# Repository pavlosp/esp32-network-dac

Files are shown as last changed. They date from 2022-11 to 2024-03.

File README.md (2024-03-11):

# ESP32-based network streamer and DAC

## Description

This is my first attempt at a simple, high-quality Digital to Analog Converter (DAC) and network streamer. Design is based around the ESP32 WiFi microcontroller, with a Texas Instruments PCM5122 high-quality DAC.

Schematic and PCB layout designed on KiCad 6.

## Schematic and PCB

Manufacturing files are included for the first iteration of the circuit board.

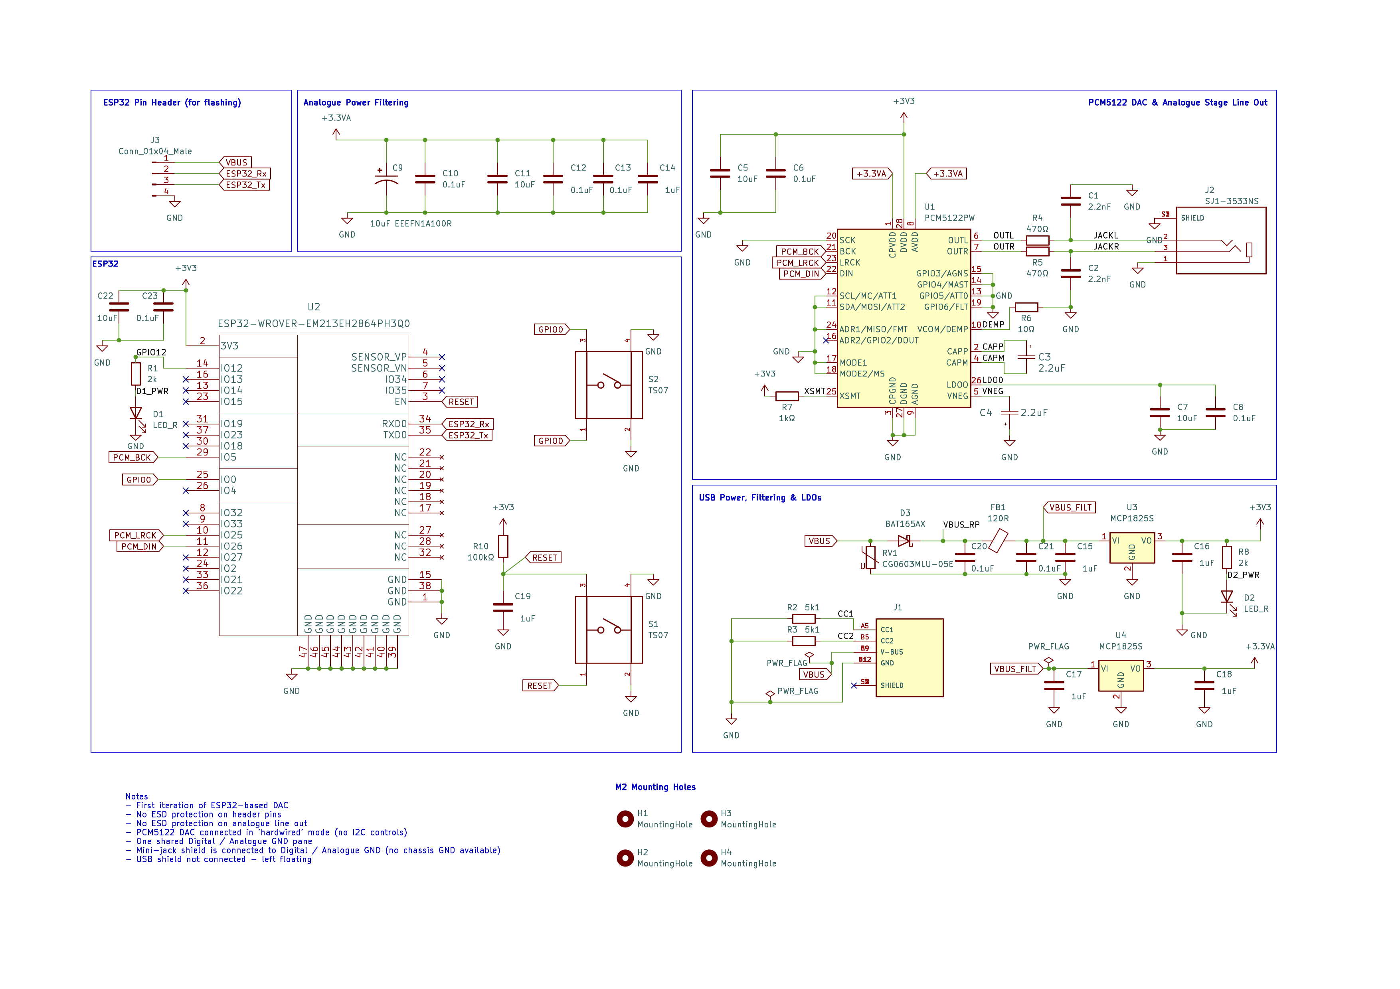
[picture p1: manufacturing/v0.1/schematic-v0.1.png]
Schematic Schematic v0.1

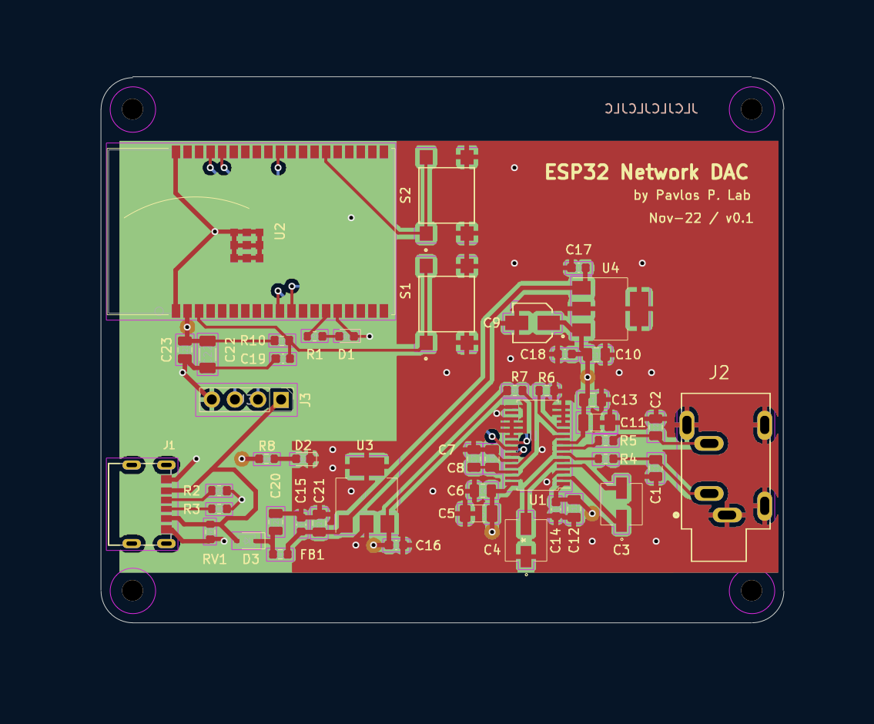
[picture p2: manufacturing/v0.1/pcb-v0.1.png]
PCB PCB v0.1


## Next steps

Refine component selection to simpler components for easier assembly (C0G capacitors).

Longer-term plan: Build on this design to build digital mixer and USB audio interface (potentially with different microcontroller from STM32 range)

## Acknowledgements

Thanks to all the online resources and reference DAC implementations (on TI data sheets). The design can be further improved of course - any suggestions, do let me know.

Many thanks to the [squeezelite-esp32](https://github.com/sle118/squeezelite-esp32) project for the software stack, which includes AirPlay and works with some configuration changes - I2S pinout configuration for digital audio data and clock signals.

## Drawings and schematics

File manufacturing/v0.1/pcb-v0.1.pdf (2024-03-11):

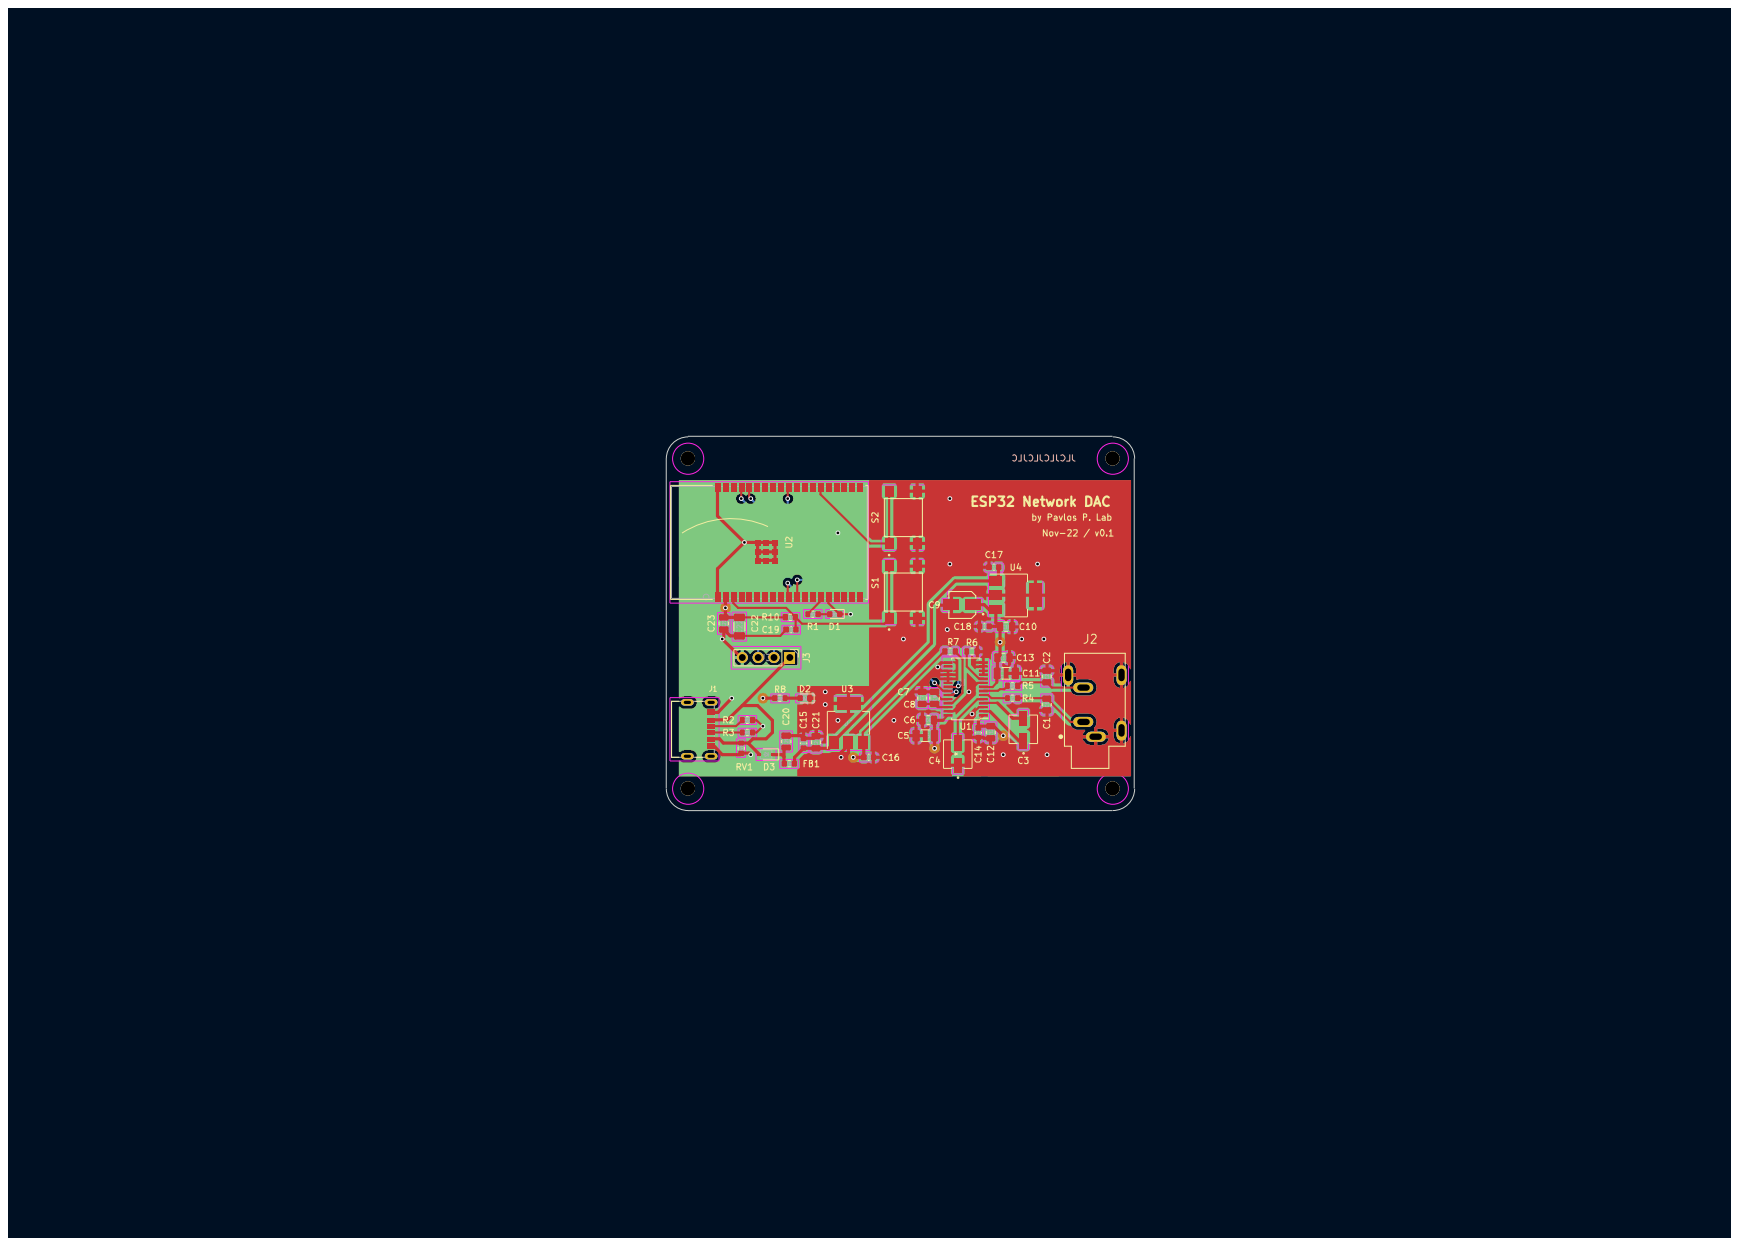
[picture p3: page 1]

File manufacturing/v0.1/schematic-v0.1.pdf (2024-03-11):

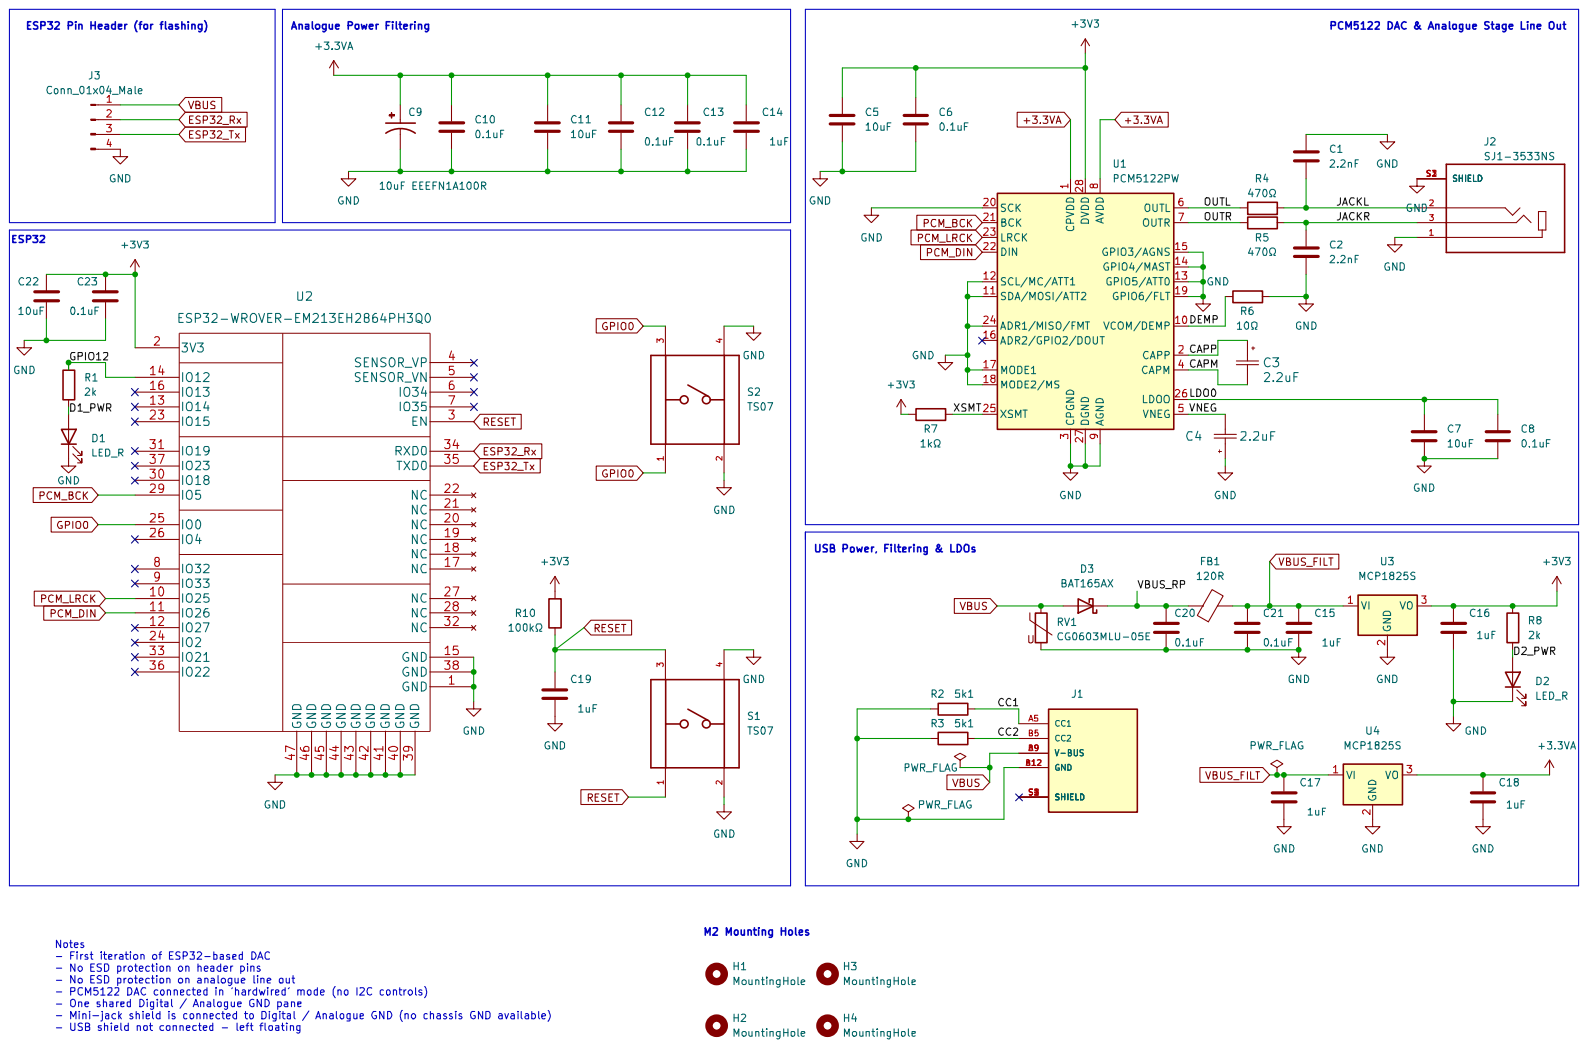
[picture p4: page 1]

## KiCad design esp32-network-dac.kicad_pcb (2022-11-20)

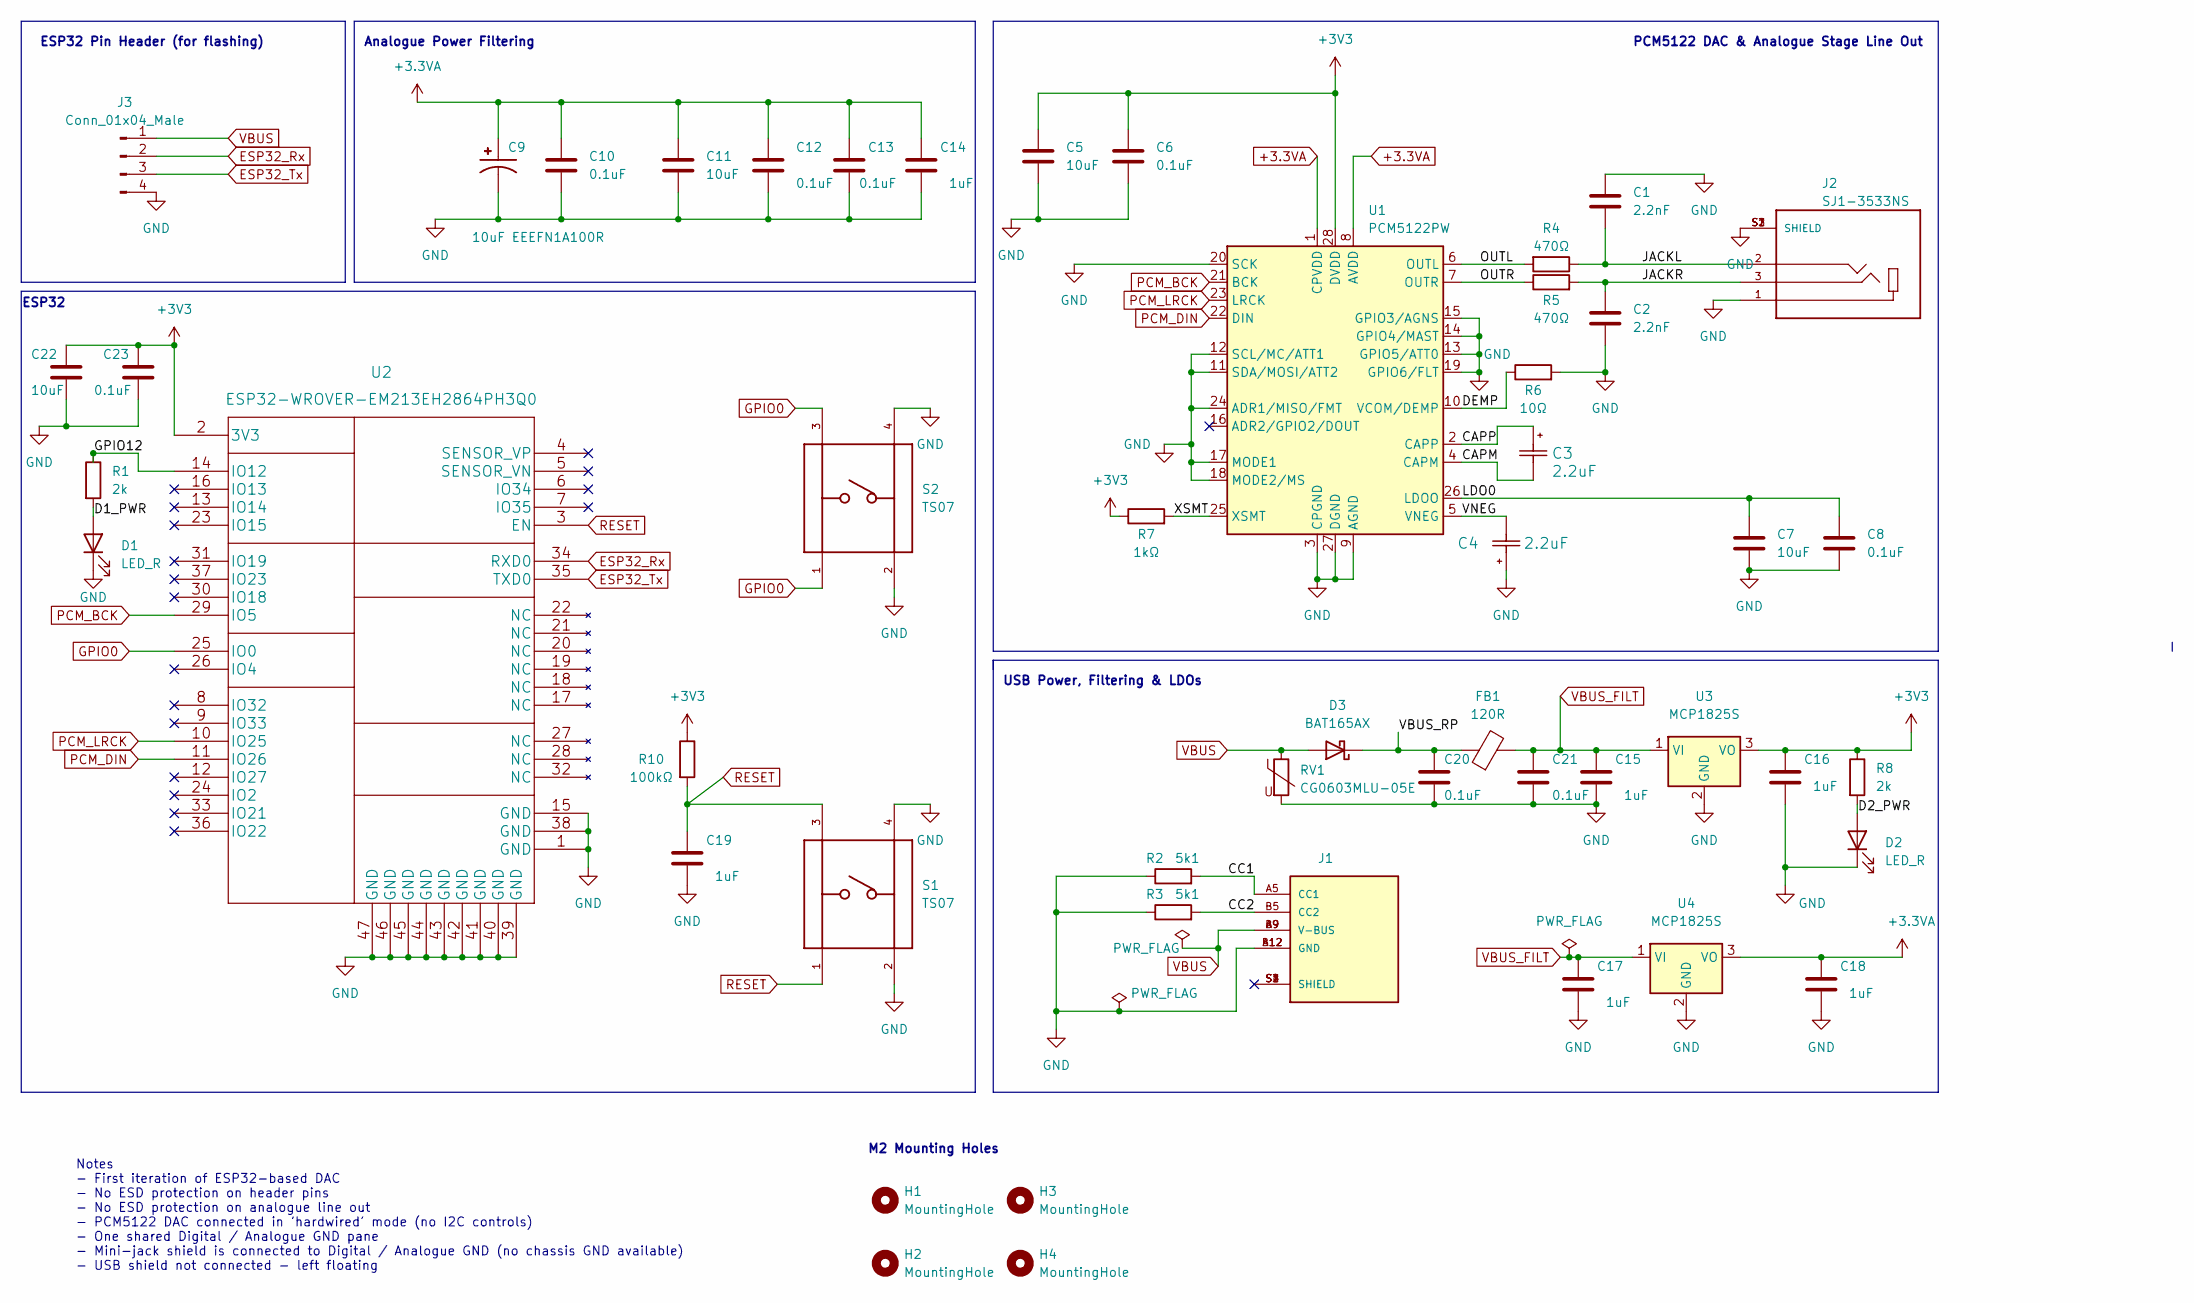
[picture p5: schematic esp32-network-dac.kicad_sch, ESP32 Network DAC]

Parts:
C1, C2: 2.2nF; C_0805_2012Metric
C3, C4: 2.2uF; UUQ1H2R2MCL1GB
C5, C11, C22: 10uF; C_1206_3216Metric
C6, C8, C10, C12, C13, C20, C21, C23: 0.1uF; C_0805_2012Metric
C7: 10uF; C_0805_2012Metric
C9: 10uF EEEFN1A100R; CAP_EEEFN1A100R; PARTREV 10-Oct-19
C14, C15, C16, C17, C18, C19: 1uF; C_0603_1608Metric
D1, D2: LED_R; LED_0603_1608Metric
D3: BAT165AX; D_SOD-323
FB1: 120R; R_0603_1608Metric
H1, H2, H3, H4: MountingHole; MountingHole_2.2mm_M2
J1: UJC-HP-3-SMT-TR; CUI_UJC-HP-3-SMT-TR; PARTREV 04/30/2020
J2: SJ1-3533NS; CUI_SJ1-3533NS
J3: Conn_01x04_Male; PinHeader_1x04_P2.54mm_Vertical
R1, R8: 2k; R_0603_1608Metric
R2, R3: 5k1; R_0603_1608Metric
R4, R5: 470Ω; R_0603_1608Metric
R6: 10Ω; R_0603_1608Metric
R7: 1kΩ; R_0603_1608Metric
R10: 100kΩ; R_0603_1608Metric
RV1: CG0603MLU-05E; R_0603_1608Metric
S1, S2: TS07; SW_TS07-667-37-BK-260-SMT-TR; PARTREV 1.0
U1: PCM5122PW; TSSOP-28_4.4x9.7mm_P0.65mm
U2: ESP32-WROVER-EM213EH2864PH3Q0
U3, U4: MCP1825S; SOT-223-3_TabPin2

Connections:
+3.3VA: C9.1, C10.1, C11.1, C12.1, C13.1, C14.1, C18.1, U1.1 (CPVDD), U1.8 (AVDD), U4.3 (VO)
+3V3: C5.1, C6.1, C16.1, C22.1, C23.1, R7.1, R8.1, R10.1, U1.28 (DVDD), U2.2 (3V3), U3.3 (VO)
/CAPM: C3.2, U1.4 (CAPM)
/CAPP: C3.1, U1.2 (CAPP)
/CC1: J1.A5 (CC1), R2.2
/CC2: J1.B5 (CC2), R3.2
/D1_PWR: D1.2 (A), R1.2
/D2_PWR: D2.2 (A), R8.2
/DEMP: R6.1, U1.10 (VCOM/DEMP)
/GPIO12: R1.1, U2.14 (IO12)
/JACKL: C1.2, J2.2, R4.1
/JACKR: C2.1, J2.3, R5.2
/LDO0: C7.1, C8.1, U1.26 (LDOO)
/OUTL: R4.2, U1.6 (OUTL)
/OUTR: R5.1, U1.7 (OUTR)
/VBUS_RP: C20.1, D3.1 (K), FB1.1
/VNEG: C4.2, U1.5 (VNEG)
/XSMT: R7.2, U1.25 (XSMT)
ESP32_Rx: J3.2, U2.34 (RXD0)
ESP32_Tx: J3.3, U2.35 (TXD0)
GND: C1.1, C2.2, C4.1, C5.2, C6.2, C7.2, C8.2, C9.2, C10.2, C11.2, C12.2, C13.2, C14.2, C15.2, C16.2, C17.2, C18.2, C19.2, C20.2, C21.2, C22.2, C23.2, D1.1 (K), D2.1 (K), J1.A12 (GND), J1.B12 (GND), J2.1, J2.S1 (SHIELD), J2.S2 (SHIELD), J2.S3 (SHIELD), J3.4, R2.1, R3.1, R6.2, RV1.2, S1.2, S1.4, S2.2, S2.4, U1.3 (CPGND), U1.9 (AGND), U1.11 (SDA/MOSI/ATT2), U1.12 (SCL/MC/ATT1), U1.13 (GPIO5/ATT0), U1.14 (GPIO4/MAST), U1.15 (GPIO3/AGNS), U1.17 (MODE1), U1.18 (MODE2/MS), U1.19 (GPIO6/FLT), U1.20 (SCK), U1.24 (ADR1/MISO/FMT), U1.27 (DGND), U2.1 (GND), U2.15 (GND), U2.38 (GND), U2.39 (GND), U2.40 (GND), U2.41 (GND), U2.42 (GND), U2.43 (GND), U2.44 (GND), U2.45 (GND), U2.46 (GND), U2.47 (GND), U3.2 (GND), U4.2 (GND)
GPIO0: S2.1, S2.3, U2.25 (IO0)
PCM_BCK: U1.21 (BCK), U2.29 (IO5)
PCM_DIN: U1.22 (DIN), U2.11 (IO26)
PCM_LRCK: U1.23 (LRCK), U2.10 (IO25)
RESET: C19.1, R10.2, S1.1, S1.3, U2.3 (EN)
VBUS: D3.2 (A), J1.A9 (V-BUS), J1.B9 (V-BUS), J3.1, RV1.1
VBUS_FILT: C15.1, C17.1, C21.1, FB1.2, U3.1 (VI), U4.1 (VI)

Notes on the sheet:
ESP32 Pin Header (for flashing)
M2 Mounting Holes
Notes - First iteration of ESP32-based DAC - No ESD protection on header pins - No ESD protection on analogue line out - PCM5122 DAC connected in 'hardwired' mode (no I2C controls) - One shared Digital / Analogue GND pane - Mini-jack shield is connected to Digital / Analogue GND (no chassis GND ava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
USB Power, Filtering & LDOs
Analogue Power Filtering
PCM5122 DAC & Analogue Stage Line Out
ESP32

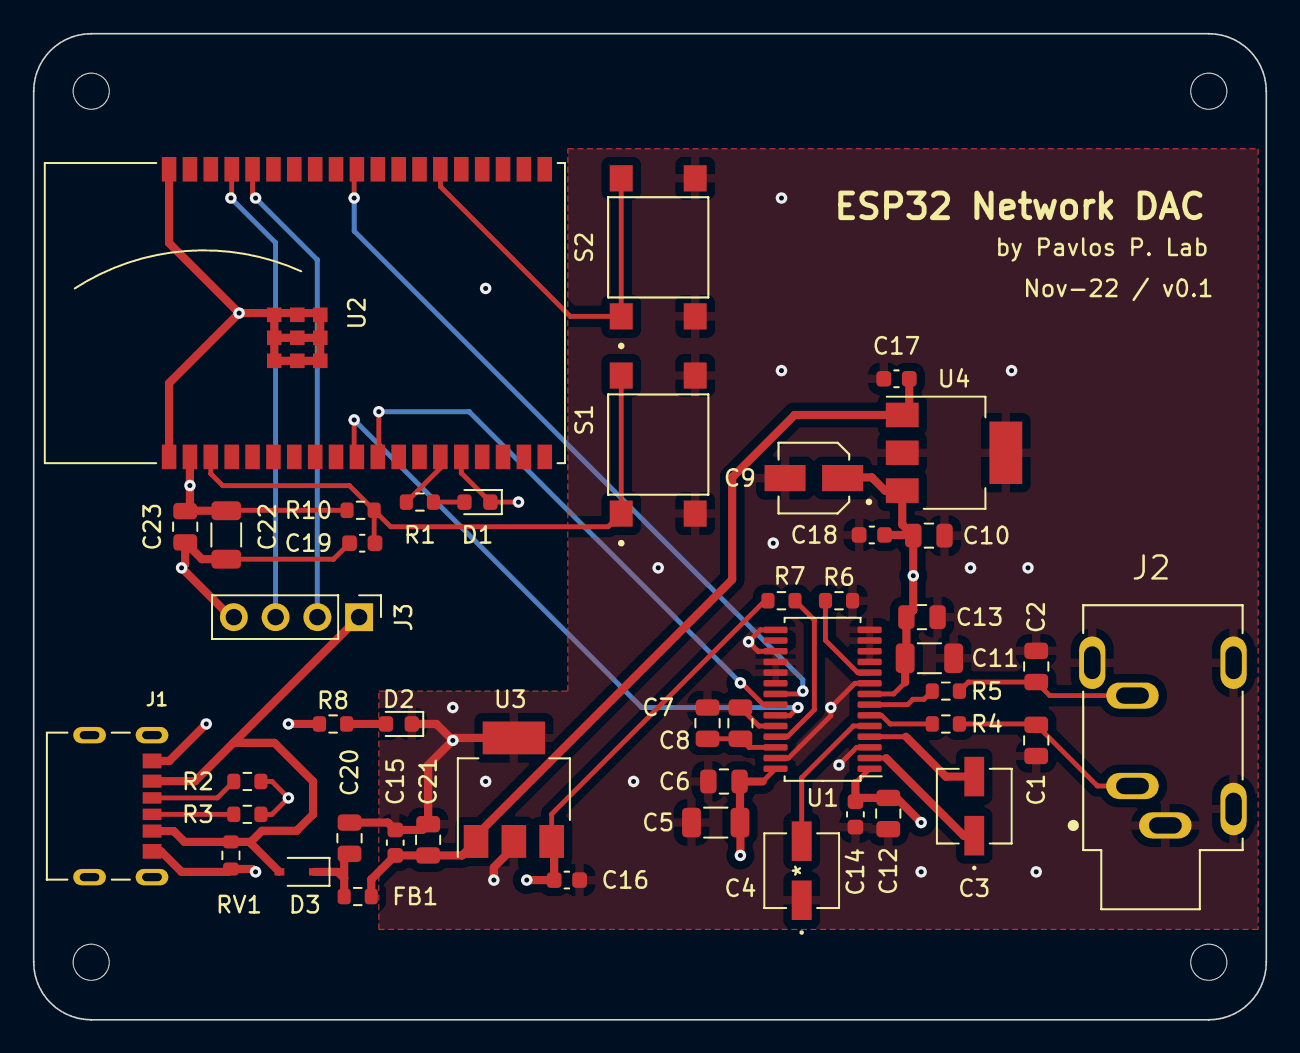
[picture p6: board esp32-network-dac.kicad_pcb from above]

Board: 4 copper layers, 75.0 x 60.0 mm, 50 parts (0 on the bottom side), 28 nets.

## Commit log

2022-04-13 added a few backups
    [esp32_streamer.kicad_sch]
2022-05-12 removed backups and started changes on USB recepticle
    [esp32_streamer.kicad_sch]
2022-08-07 minor update on text label TODO
    [esp32_streamer.kicad_sch]
2022-11-05 Added new LDO, USB connector and ESD protection on USB power line
    [esp32_streamer.kicad_pcb, esp32_streamer.kicad_sch]
2022-11-05 Updates to schematic - nearly complete
    [esp32_streamer.kicad_sch]
2022-11-06 Updates and fixes based on ERC checks
    [esp32_streamer.kicad_sch]
2022-11-06 Added PCB first iteration - placed components in a logical layout
    [esp32_streamer.kicad_pcb]
2022-11-06 Added more traces and a ground plane
    [esp32_streamer.kicad_pcb, esp32_streamer.kicad_sch]
2022-11-07 Continued working on PCB - most traces laid out. Need to adhere to DRC rules though
    [esp32_streamer.kicad_pcb]
2022-11-08 Fixes to footprints and added more traces. Need to fix all DRC errors & warnings next.
    [esp32_streamer.kicad_pcb, esp32_streamer.kicad_sch]
2022-11-12 Sensible changes to grid and component placement for DAC (following TI datasheet)
    [esp32_streamer.kicad_pcb, esp32_streamer.kicad_sch]
2022-11-12 Analog DAC components now laid out properly (hopefully).
    [esp32_streamer.kicad_pcb, esp32_streamer.kicad_sch]
2022-11-12 Updated PCB layout - now it looks cleaner - completed layout. next step: traces
    [esp32_streamer.kicad_pcb, esp32_streamer.kicad_sch]
2022-11-12 Updated name to ESP32 Network DAC (local KiCad files and github)
    [esp32-network-dac.kicad_pcb, esp32-network-dac.kicad_sch]
2022-11-13 Updates to PCB - traces all done and most ground planes etc.
    [esp32-network-dac.kicad_pcb]
2022-11-13 Changed footrpints to remove DRC warnings. Added board outline.
    [esp32-network-dac.kicad_pcb, esp32-network-dac.kicad_sch]
2022-11-14 Updates to USB C receptive - replaced mid-mount recepticle with SMT
    [esp32-network-dac.kicad_pcb, esp32-network-dac.kicad_sch]
2022-11-20 Finalised v0.1 design and created manufacturing files
    [esp32-network-dac-B_Cu.gbr, esp32-network-dac-B_Mask.gbr, esp32-network-dac-B_Paste.gbr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]
2024-03-11 Added schematic and PCB board picture on README

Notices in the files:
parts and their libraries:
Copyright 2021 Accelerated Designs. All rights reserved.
